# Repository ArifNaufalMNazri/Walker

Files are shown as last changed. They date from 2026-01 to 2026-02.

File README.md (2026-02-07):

# Walker

<p align="center"> 
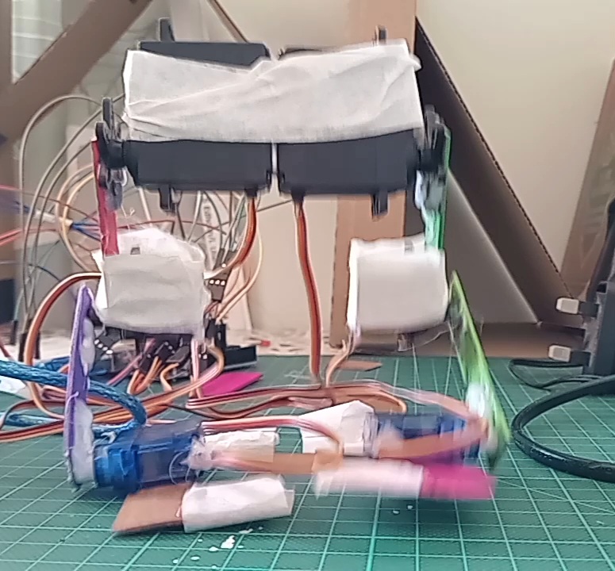
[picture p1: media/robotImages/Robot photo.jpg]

</p>

## Project Overview 🔍
I created a 2-legged walking robot to learn how inverse kinematics works, robot design, and motor control. This project is intended as an experiment to explore robotics and moving systems. 

## Repository files 📁
- /designs: Designs for the robot, including sketches and CAD
- /code: Test code for the robot
- /media: Photos and videos of tests

## Problems I solved & Build process🗒️

### Design

- I had to come up with designs for the robot. I started with an initial sketch of the robot, shown in the link below.

➡️ [View Iteration 1](https://github.com/ArifNaufalMNazri/Walker/blob/main/designs/iteration1/README.md)

- I represented the drawing in CAD to better visualize it. 

➡️[View Iteration 2](https://github.com/ArifNaufalMNazri/Walker/blob/main/designs/iteration2/README.md)

### Leg Prototype

- With the design completed, I moved on to building a prototype leg to test movement. 

➡️[View Iteration 1](https://github.com/ArifNaufalMNazri/Walker/blob/main/protoLeg/iteration1/README.md)

- I conducted button tests with the leg to see how each servo moved. 

➡️[View Iteration 2](https://github.com/ArifNaufalMNazri/Walker/blob/main/protoLeg/iteration2/README.md)

- Kinematics equations were derived and implemented into the program. A new stand for leg testing was built to test more dynamic movement.

➡️[View Iteration 3](https://github.com/ArifNaufalMNazri/Walker/blob/main/protoLeg/iteration3/README.md)

- The hip servo was not handling the weight well, so it was replaced witha stronger servo. New stand made of cardboard was made for transportability.

➡️[View Iteration 4](https://github.com/ArifNaufalMNazri/Walker/blob/main/protoLeg/iteration4/README.md)

- The calculations for movement in the negative x-axis were corrected and a basic triangle-stepping sequence was tested

➡️[View Iteration 5](https://github.com/ArifNaufalMNazri/Walker/blob/main/protoLeg/iteration5/README.md)

- I added the ankle servo and calculated new equations to determine its angle in space

➡️[View Iteration 6](https://github.com/ArifNaufalMNazri/Walker/blob/main/protoLeg/iteration6/README.md)

### Final Robot
I connected the two servos with duct tape and used a new stepping sequence for walking. Finally, the robot walked as intended, albeit shakily. The experiment was deemed a success. 

<p align="center">
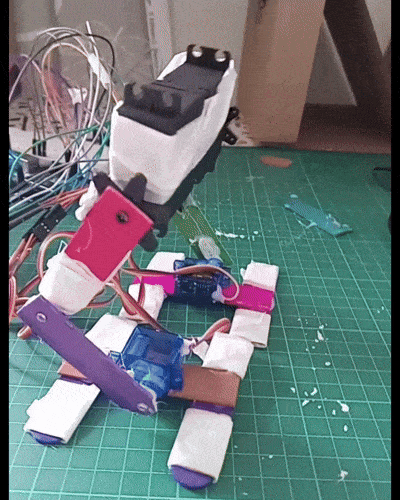
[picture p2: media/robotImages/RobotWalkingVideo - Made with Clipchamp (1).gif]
  
</p>

Link to code: ➡️[View Code](https://github.com/ArifNaufalMNazri/Walker/blob/main/WalkerCode.ino)

## Last thoughts 🧠
I am glad that the robot managed to walk on its own two feet. It is my first experiment into moving robot systems, so I was not surprised it came off a bit shaky. The problems I solved, however, taught me a lot about trigonometry, code, inverse kinematics and motor control. I plan to use this knowledge and more to create even better projects in the future. That's all from me for now. Thank you for reading.

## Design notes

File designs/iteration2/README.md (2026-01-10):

# Iteration2-CAD design using FreeCAD

## Sample image 
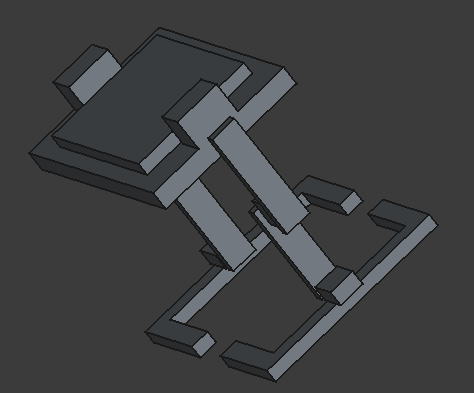
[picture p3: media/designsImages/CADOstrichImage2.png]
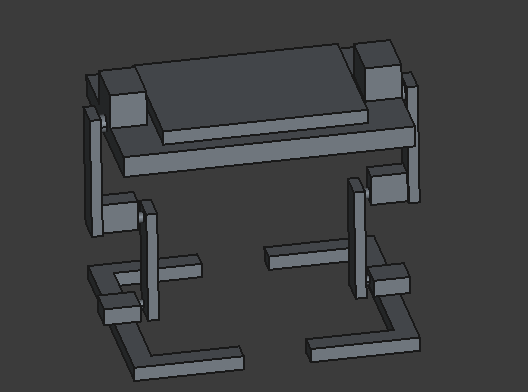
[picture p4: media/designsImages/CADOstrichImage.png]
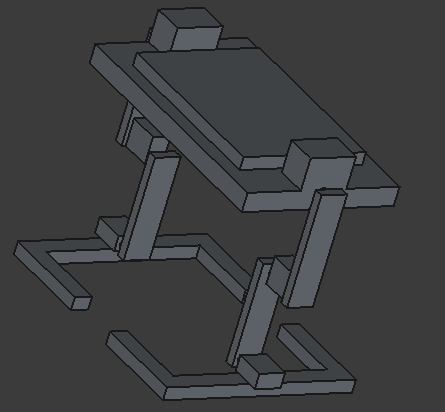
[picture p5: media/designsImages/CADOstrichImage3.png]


CAD file link: [CADFile](https://github.com/ArifNaufalMNazri/Walker/blob/main/designs/iteration2/ProjectOstrich.step)

<i>Access file in FreeCAD</i>

## Description
-The flat rectangle on top of the robot is meant to represent the **Arduino UNO**

-The feet was designed based on toy robots to **improve stability and reduce weight**

-The cuboids with cylinders popping out represent the **servos**

## What's next
I'm satisfied with how the design looks. I think this is the end of my first design process, and I'll now proceed to building a **prototype leg.**

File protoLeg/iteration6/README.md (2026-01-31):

# Third servo-Update servo angle functions-Angle orientation-Second leg
A lot happened in this iteration. Let's go through them one by one. 
## Third servo
I added the third servo by orienting it at 90 degrees and putting it on its side, screwing it into the leg. 
<p align="center">
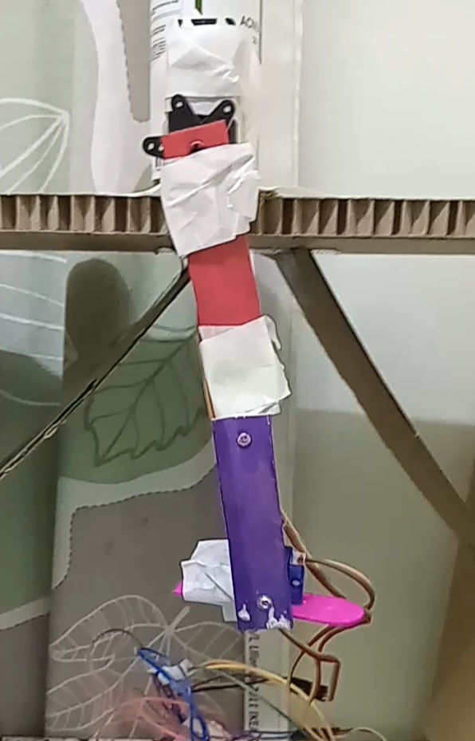
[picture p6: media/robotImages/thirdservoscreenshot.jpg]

</p>

## Update servo angle functions
I created new functions to update the servos positions so they all can change at the same rate. They are called `step()` and `updateAngle()`
Further explanations are in comments in the code. 
<p align="center">
  
<i>step()</i>
  
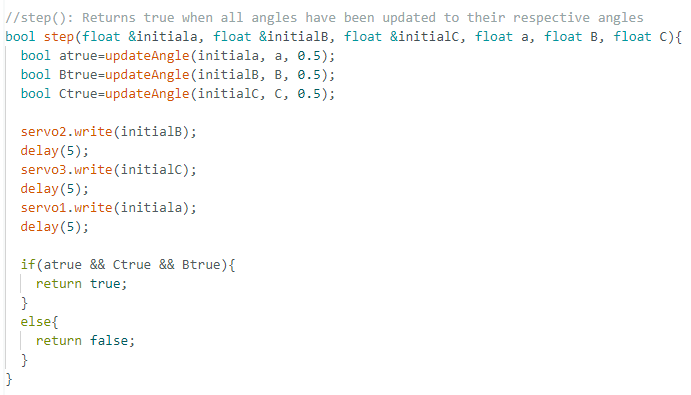
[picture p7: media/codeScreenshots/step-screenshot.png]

</p>

<p align="center">
  
<i>updateAngle()</i>

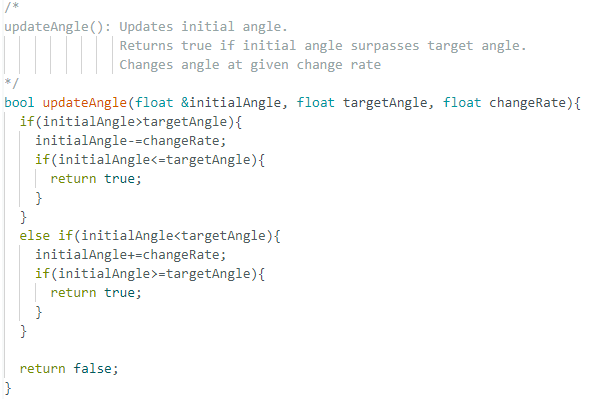
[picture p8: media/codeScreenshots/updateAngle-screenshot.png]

</p>

[Get code here](https://github.com/ArifNaufalMNazri/Walker/blob/main/code/legTestsCode2/legTests.ino)

## Angle orientation
I changed the leg lengths to be equal to form an isosceles triangle, making the calculations easier. I first started with updating the third servo angle as the leg was straight. 

<p align="center">
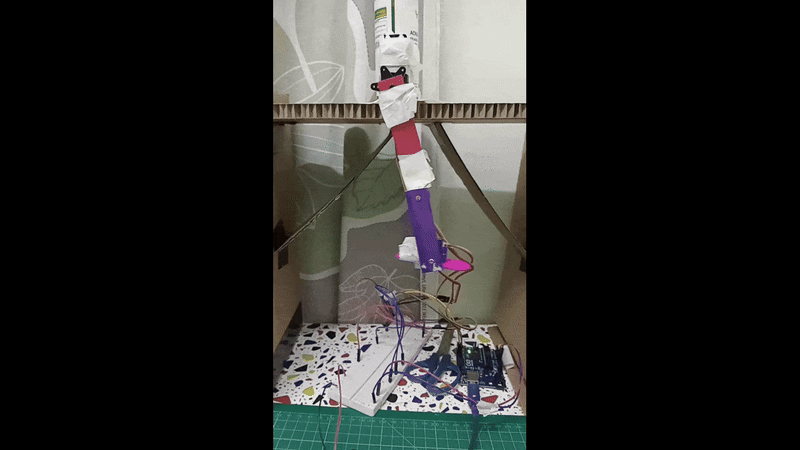
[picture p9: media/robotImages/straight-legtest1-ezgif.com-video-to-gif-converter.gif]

</p>

Once I finished orienting that, I moved on to making the leg move up and down and maintaing the third servos parallel angle against the ground. 

<p align="center">
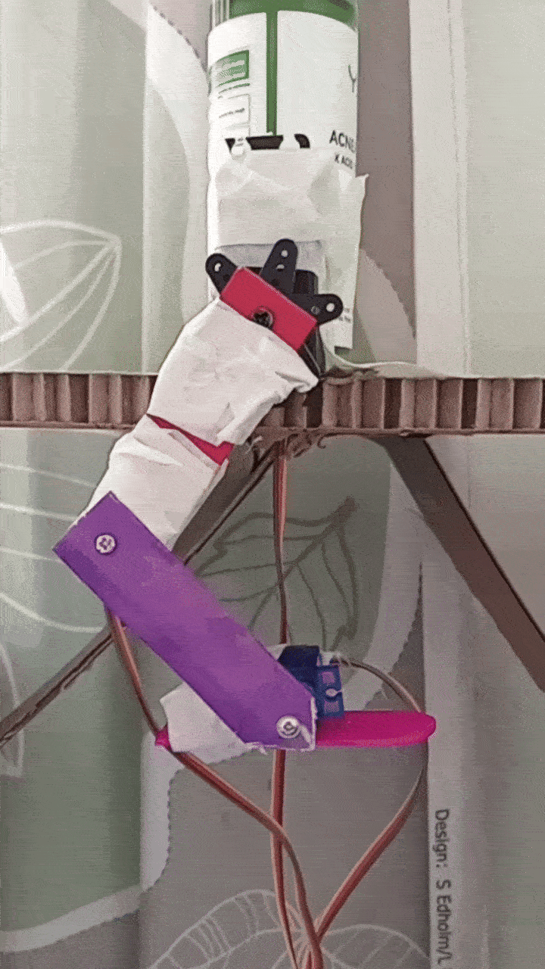
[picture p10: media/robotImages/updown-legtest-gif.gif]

</p>

By adding a function `findC()` into the kinematics file, I could calculate the angle for the third servo.

<p align="center">

<i>findC</i>

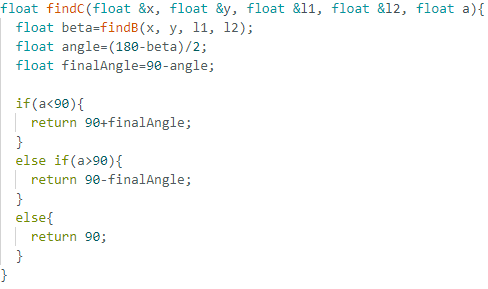
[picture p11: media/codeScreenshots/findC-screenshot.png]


</p>

## The second leg 
After I finished orienting the angles of the third servo, I built an identical leg as the first one to serve as the second leg
<p align="center">
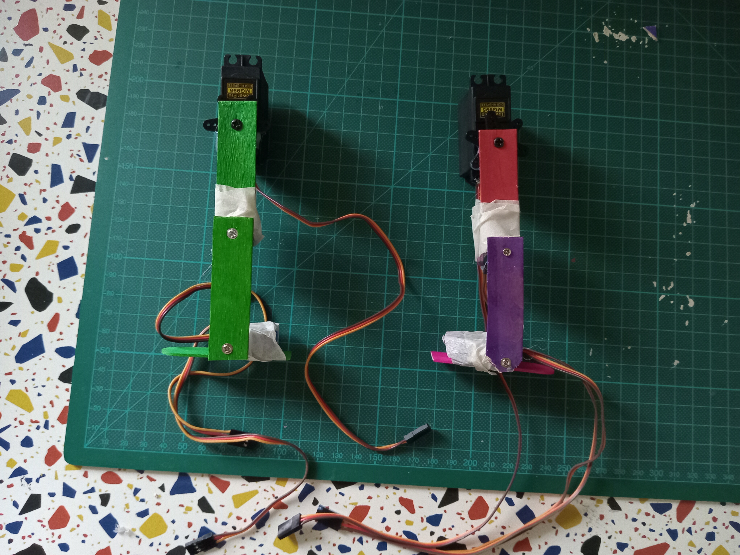
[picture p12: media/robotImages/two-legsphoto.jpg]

  
<i>Second leg on left, first leg on right</i>
</p>

## What's next
I am going to do some final tests with the first and second leg to see whether all the angles are calculated correctly. Then, afterwards, I'll start building the actual robot. The project is nearing completion.

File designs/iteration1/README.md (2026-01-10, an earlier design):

# Iteration1-First Ideas
## What I wanted
I wanted to make a something simple that I knew could walk and stand upright. Searching through the internet gave me some ideas for early sketches, like the Leggy and the Ducky.

## Design Idea
Eventually, I was inspired by the way ostriches moves, and hence, I designed the Ostrich based on its leg movements. The leg is designed to bend inwards, which might present a challenge for generating the walking sequence. Nevertheless, I have chosen this design: 

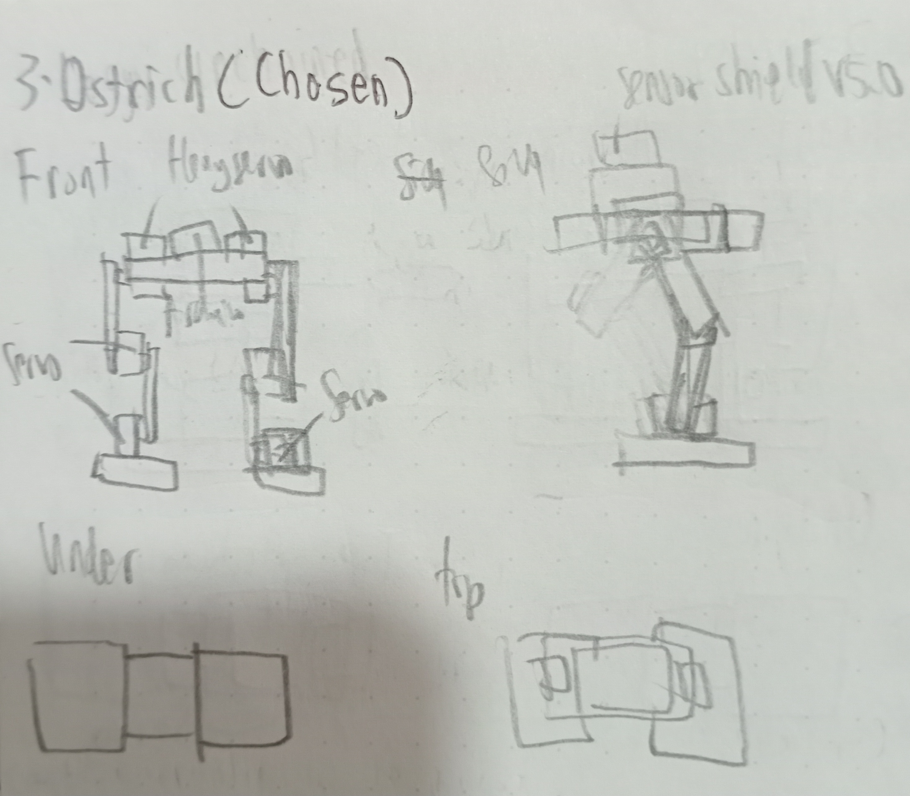
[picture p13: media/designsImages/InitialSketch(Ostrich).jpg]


### The previous sketches
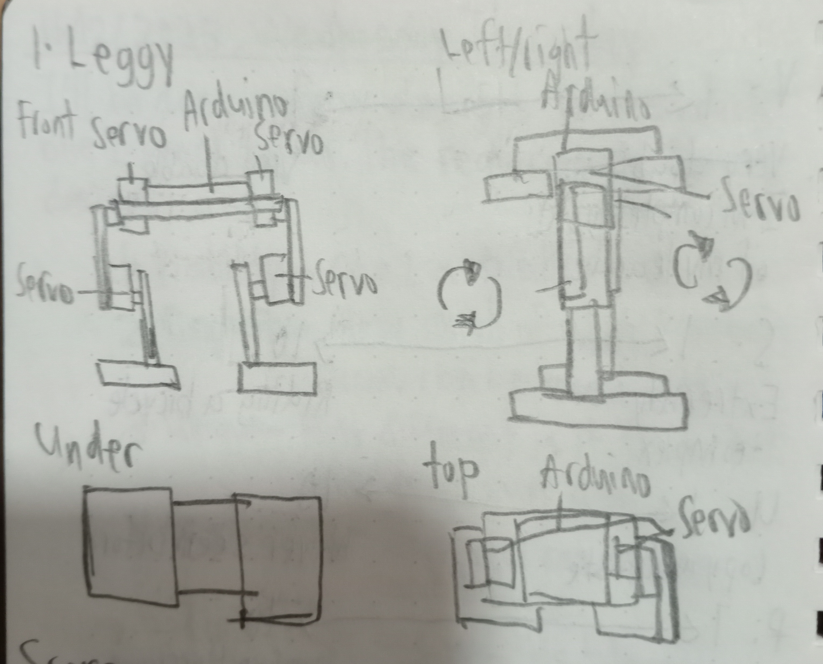
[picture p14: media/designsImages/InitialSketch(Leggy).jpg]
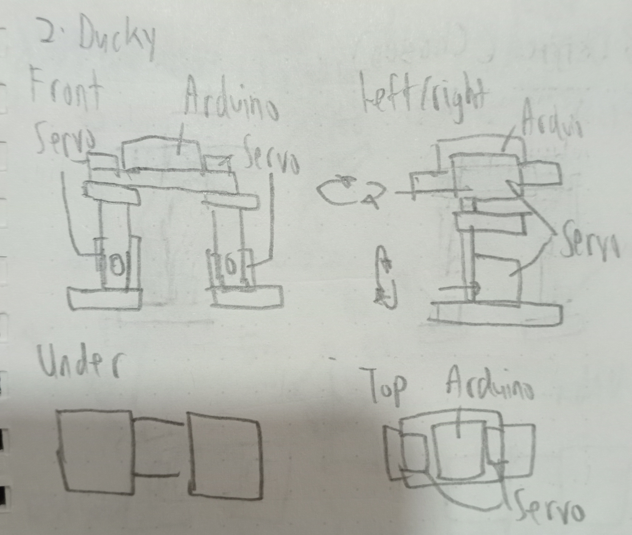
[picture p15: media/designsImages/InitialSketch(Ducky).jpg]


## What Next?
I'll try making a CAD of this sketch so I can practice my CAD skills and see a 3d model of the robot itself

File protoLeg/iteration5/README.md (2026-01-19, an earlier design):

# Stepping tests--Negative x_axis and Triangle Step
I adjusted my code so that I could make the leg move in the negative x-axis, tried out a triangular stepping sequence, and adjusted my stand
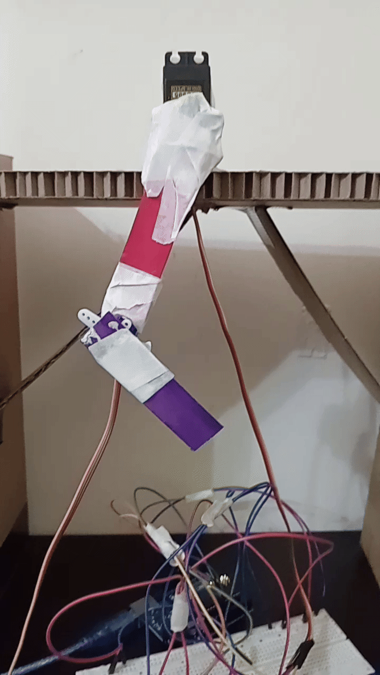
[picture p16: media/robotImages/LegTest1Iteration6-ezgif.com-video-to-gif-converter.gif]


## Adjusting my stand
I added supports underneath my stand so it would not shake as theleg swung
<p align="center">
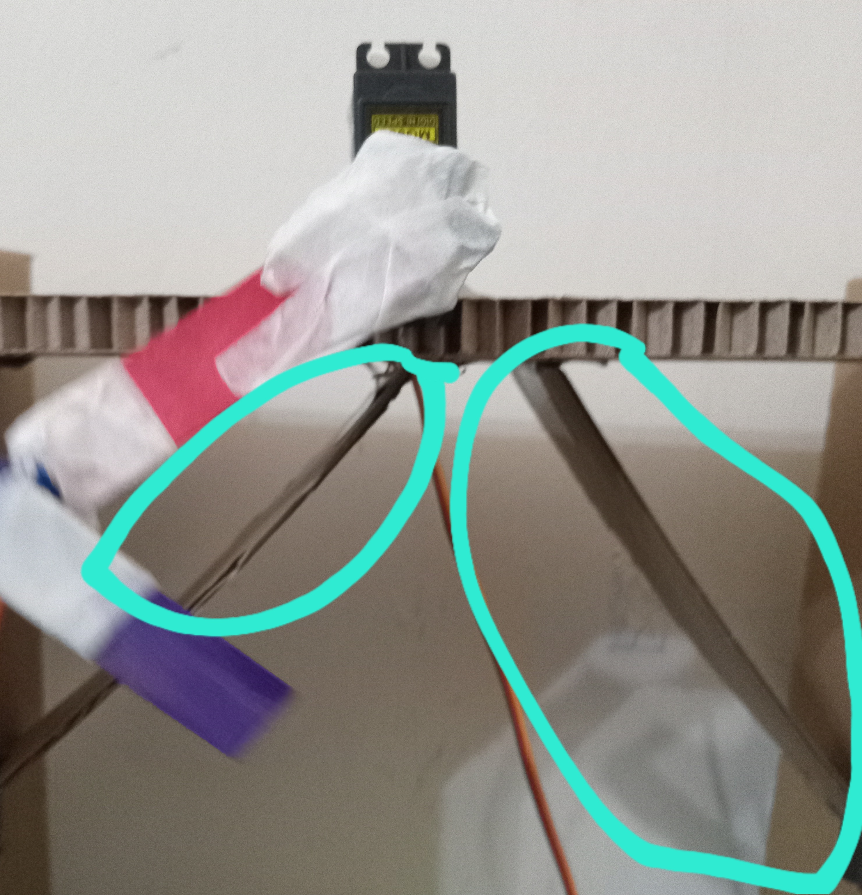
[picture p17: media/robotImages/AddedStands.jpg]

</p>

## Code adjustments
I changed how my code took in -x values so that it would return a different value for the servo angles. BY changing what angles I took and what I subtracted, I was able to correctly transalate the position of the foot in the -x axis. 
<p align="center">
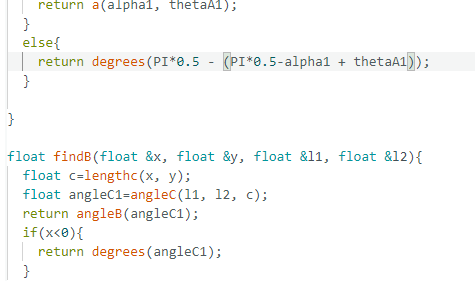
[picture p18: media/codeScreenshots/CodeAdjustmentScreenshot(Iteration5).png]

</p>

| Positive x-axis | Negative x-axis |
|:---:|:---:|
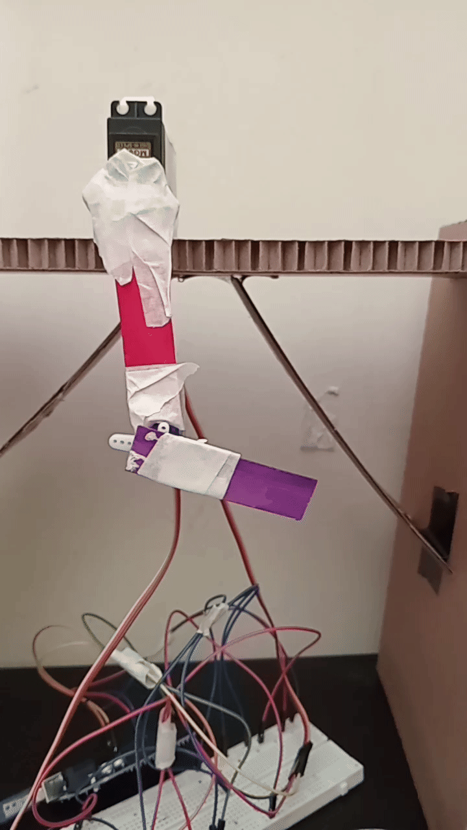
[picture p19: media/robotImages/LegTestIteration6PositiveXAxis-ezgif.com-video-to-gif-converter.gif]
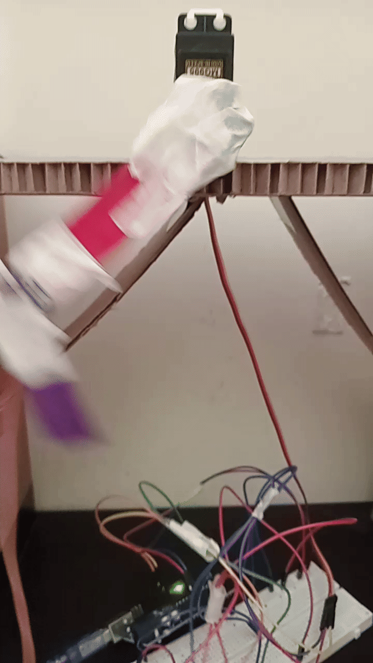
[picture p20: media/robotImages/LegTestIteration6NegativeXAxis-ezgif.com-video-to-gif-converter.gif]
|||

## Triangle Stepping Sequence
Afterwards, I created a function that took two x and y values, one for the triangles step, and one for the homing step. The triangle step caused the foot to move in a triangle based on the kinematics calculations. The homing step gave the triangle the third point it needed to create a triangle, and also served as an anchor position for the foot for reference. 
<p align="center"><i>Triangle step function</i></p>
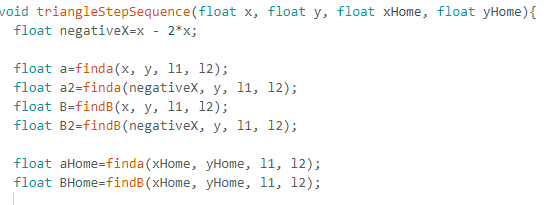
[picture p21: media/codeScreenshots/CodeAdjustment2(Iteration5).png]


<p align="center"><i>Leg triangle step(Video was cut off, but the actual video shows the leg moving to its homing position after travelling to the -x axis</i></p>
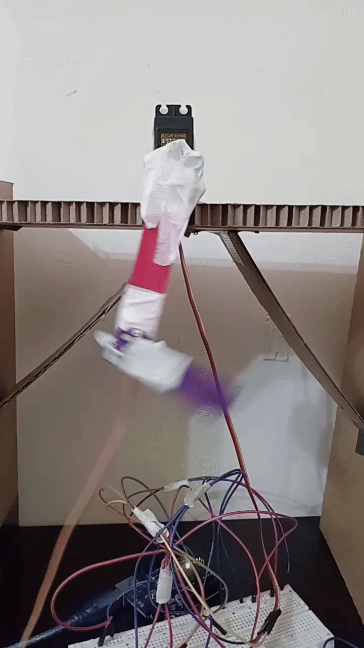
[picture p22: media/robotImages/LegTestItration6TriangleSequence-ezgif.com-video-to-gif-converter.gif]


## What's next
I'm planning on finally integrating the foot servo into the leg. I'll have to create new functions and workout new equations to allow the foot to always maintain its 90 degree angle position. 
- Integrate 3rd Servo to leg
- Create new kinematics equation to allow 3rd servo to maintain 90 degree orientation
- Transalate calculations into code

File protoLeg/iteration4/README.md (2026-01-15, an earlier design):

# Iteratioin4-New Stand 2 and New Servo
## The new stand-Part 2
I built a new stand made of cardboard I had from Ikea-furniture packaging. It was designed to be **stable** and **transportable**. I like how comfortable and easy it is to bring around now. 

| Front View | Left View | Right-Top View |
|:---:|:---:|:---:|
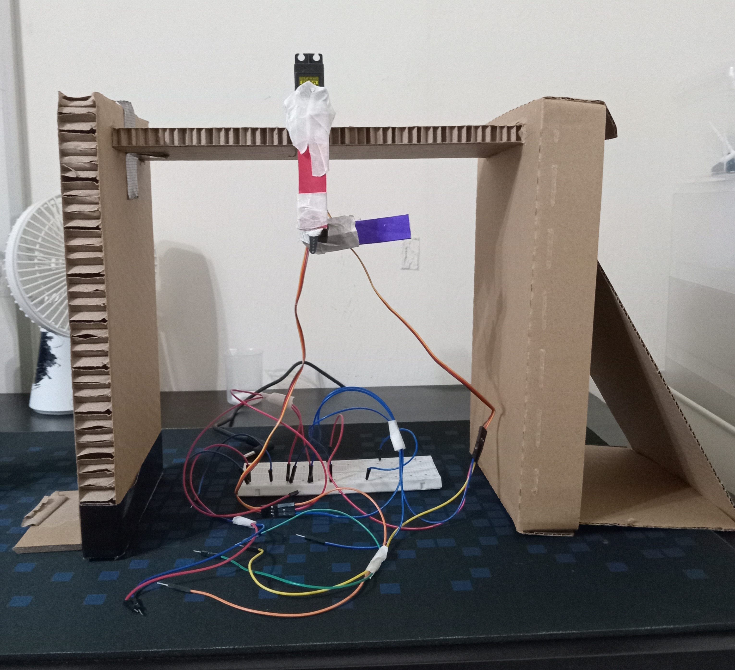
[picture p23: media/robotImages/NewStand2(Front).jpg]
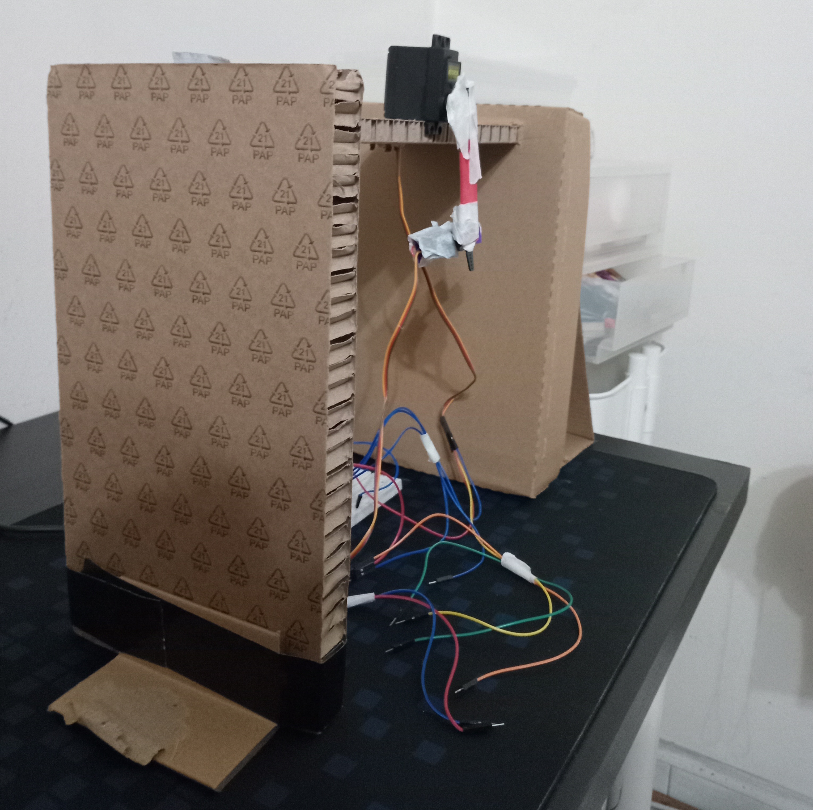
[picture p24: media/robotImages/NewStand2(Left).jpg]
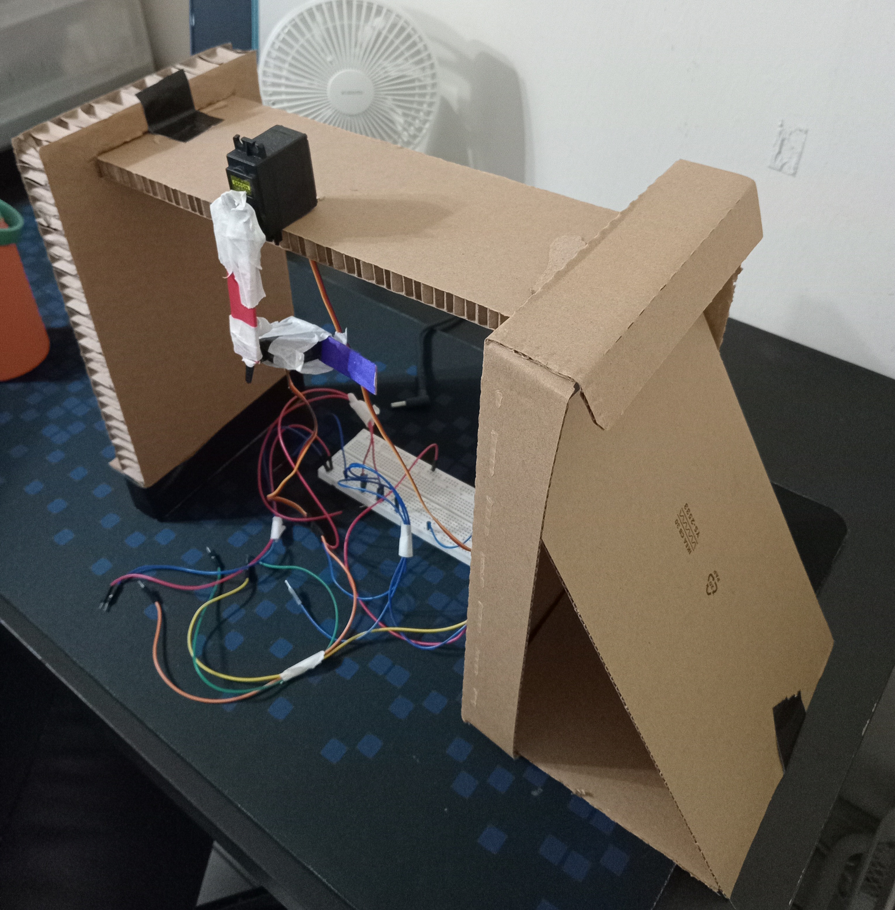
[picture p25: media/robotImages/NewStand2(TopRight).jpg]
||||

## The new Servo
I bought a stronger servo for the hip servo, and used the previous hip servo as the now knee servo

<p align="center">
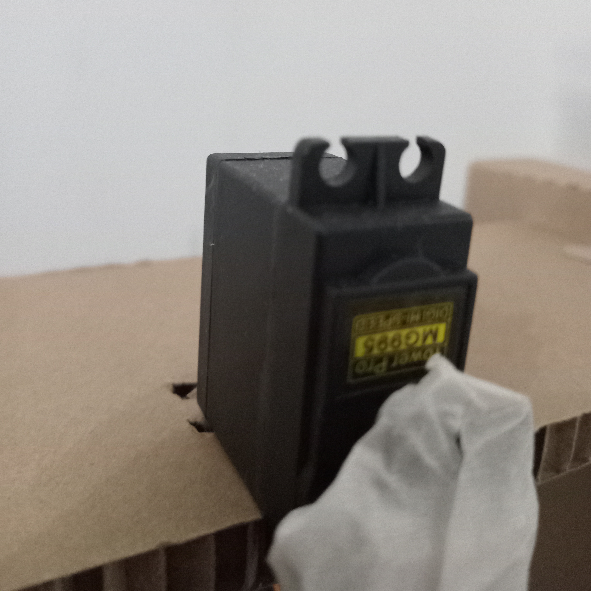
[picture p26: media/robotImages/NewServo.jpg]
  
</p>

## What's next
- Test the kinematics program on the new leg
- Make adjustments as needed
- Reintegrate the foot joint

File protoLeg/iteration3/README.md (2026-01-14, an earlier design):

# Iteration3-Test Kinematics and New Leg Stand
## Kinematics calculations
I needed a way to calculate the angles the servos needed to turn in order to change the foot's position. In order to do that, I ignored the turning the foot for now and focused more on turning the hip and knee servos. Here are the diagrams of my calculations: 

<p>




</p>

<i>Images clearer in media folder</i>

## Description
I used **cosine** and **sin** rules in my calculations, along with a coordinate system to get the desired angles. All the angles calculated lead up to the calculation of angle a and b. I also broke down the calculations step by step, which made it easier for me to transalate it into code. 



## Changing the leg stand
I realized the leg stand I used on my cupboard was too flimsy, so I changed it to balance on a stick laying between a lamp and a tissue box, which do not appear in this photo. 

<p align="center">
  <i>Old stand</i>
</p>
<p align="center">

</p>

<p align="center">
  <i>New stand</i>
</p>
<p align="center">

</p>

## Problems encountered
- **Hip** servo too **weak** to carry weight of leg and **jitters**. Need to replace with stronger servo
- New stand **uncomfortable** to move around and **weak**. Need to build a stronger one.
- Remove ankle servo for testing

## What's next
- Buy a **stronger servo** to replace the hip servo.
- Build **new stand** for leg testing

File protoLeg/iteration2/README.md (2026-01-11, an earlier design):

# Iteration2-Button test on first prototype leg
## Sample video


## Description

- Attached the leg to a cupboard so leg movement could be seen

- Moved each joint during testing (ankle joint movement not shown in video)

- Link to code: [View code](https://github.com/ArifNaufalMNazri/Walker/blob/main/code/legButtonTest.ino)

## Problems encountered
The knee servo moved in the <i>opposite</i> direction to the other servos because of its orientation. This prevented me from creating a function that would update the angle of the servos, so I resorted to this long chain of <i>if-else statements</i>: 



## What's next
I'm currently happy with how the leg moves. I'll leave the servo orientation as it is now, but I might have to change it in the future. Next, I'll work on: 
- Inverse kinematics calculations
- Putting the inverse kinematics calculations into code

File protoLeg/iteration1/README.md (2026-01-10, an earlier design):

# Iteration 1-First Prototype Leg
## Sample image


## Description
-Two SG90 Servos

-One MG90 Servo

-Three popsicle sticks

I used an MG90 servo as the **hip servo**, and the 2 SD90 servos for the **knee** and **ankle** joints. The popsicles of the femur and tibia were both **7cm**, while the foot was of **unrecorded** length

## Up next
Now, I want to attach this to the arduino and write a simple program to change the angles of the servos by pushing **buttons**. It will help me to see what positions I want the leg to move to, and confirm whether the leg can move as expected.

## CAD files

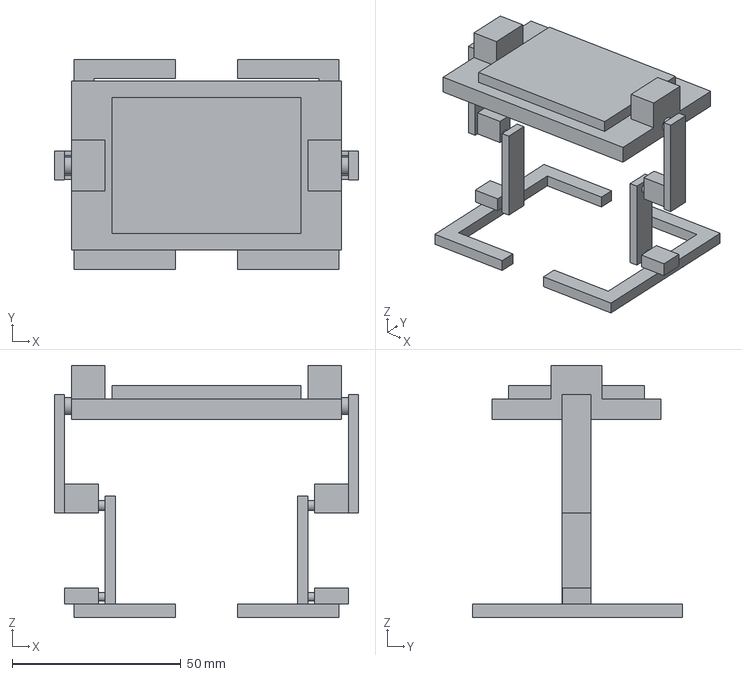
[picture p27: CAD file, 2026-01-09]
designs/iteration2/ProjectOstrich.step
90.0 x 62.2 x 74.7 mm

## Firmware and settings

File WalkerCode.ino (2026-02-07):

#include "kinematics.h"
#include <Servo.h>

//Servo pins
const int ServoPin1=8;
const int ServoPin2=9;
const int ServoPin3=10;
const int ServoPin4=5;
const int ServoPin5=6;
const int ServoPin6=7;

//Servo objects
Servo servo1;
Servo servo2;
Servo servo3;
Servo servo4;
Servo servo5;
Servo servo6;

//Length of legs. Equal to form isosceles triangle
float l1=5.2;
float l2=5.2;

//Initial position of servos
float initialx=0;
float initialy=-9;

float x=2;
float y=-6;

float x2=3;
float y2=-9;

void setup() {

  servo1.attach(ServoPin1);
  servo2.attach(ServoPin2);
  servo3.attach(ServoPin3);
  servo4.attach(ServoPin4);
  servo5.attach(ServoPin5);
  servo6.attach(ServoPin6);

  float a=finda(initialx, initialy, l1, l2);
  float B=findB(initialx, initialy, l1, l2);
  float C=findC(initialx, initialy, l1, l2, a);

  servo1.write(a);
  servo2.write(B);
  servo3.write(C);
  servo4.write(180-a);
  servo5.write(180-B);
  servo6.write(180-C);

  delay(1000);

}


/*
updateAngle(): Updates initial angle. 
               Returns true if initial angle surpasses target angle. 
               Changes angle at given change rate
*/
bool updateAngle(float &initialAngle, float targetAngle, float changeRate){
  if(initialAngle>targetAngle){
    initialAngle-=changeRate;
    if(initialAngle<=targetAngle){
      return true;
    }
  }
  else if(initialAngle<targetAngle){
    initialAngle+=changeRate;
    if(initialAngle>=targetAngle){
      return true;
    }
  }

  if(initialAngle==targetAngle){
    return true;
  }

  return false;
}


//step(): Returns true when all angles have been updated to their respective angles
bool step(float &initiala, float &initialB, float &initialC, float a, float B, float C, int mode){
  bool atrue=updateAngle(initiala, a, 0.5);
  bool Btrue=updateAngle(initialB, B, 0.5);
  bool Ctrue=updateAngle(initialC, C, 0.5);

  float delaytime=3;
  
  if(mode==1){
  servo2.write(initialB);
  delay(delaytime);
  servo3.write(initialC);
  delay(delaytime);
  servo1.write(initiala);
  delay(delaytime);
}
else if(mode==2){
  servo5.write(180-initialB);
  delay(delaytime);
  servo6.write(180-initialC);
  delay(delaytime);
  servo4.write(180-initiala);
  delay(delaytime);
}
  if(atrue && Ctrue && Btrue){
    return true;
  }
  else{
    return false;
  }
}

//Initial angles of servos
float initiala=90;
float initialB=0;
float initialC=90;

float initiala2=90;
float initialB2=0;
float initialC2=90;

float delaytime=30;

void loop() {
    //First coordinate
    float a=finda(x, y, l1, l2);
    float B=findB(x, y, l1, l2);
    float C=findC(x, y, l1, l2, a);

    //Second coordinate
    float a2=finda(x2, y2, l1, l2);
    float B2=findB(x2, y2, l1, l2);
    float C2=findC(x2, y2, l1, l2, a2);
    
    //Third coordinate
    float a3=finda(initialx, initialy, l1, l2);
    float B3=findB(initialx, initialy, l1, l2);
    float C3=findC(initialx, initialy, l1, l2, a3);
    
    while(true){
      bool legCondition=step(initiala, initialB, initialC, a, B, 140, 1);
      if(legCondition){
        break;
      }
    } 
    
    delay(delaytime);
  
    while(true){
      bool legCondition=step(initiala, initialB, initialC, a2, B2, C2, 1);
      if(legCondition){
        break;
      }
    } 

    delay(delaytime);

    while(true){
      bool legCondition=step(initiala, initialB, initialC, a3, B3, C3, 1);
      bool legCondition2=step(initiala2, initialB2, initialC2, a, B, 140, 2);
      if(legCondition && legCondition2){
        break;
      }
    } 
    
    delay(delaytime);

    while(true){
      bool legCondition=step(initiala2, initialB2, initialC2, a2, B2 ,C2, 2);
      if(legCondition){
        break;
      }
    } 
    
    delay(delaytime);

    while(true){
      bool legCondition=step(initiala2, initialB2, initialC2, a3, B3, C3, 2);
      bool legCondition2=step(initiala, initialB, initialC, a, B, 140, 1);
      if(legCondition && legCondition2){
        break;
      }
    } 
    
    delay(delaytime);
  
}

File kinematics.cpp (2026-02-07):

#include "kinematics.h"

float limit(float x){
  return max(min(x, 1.0), -1.0);
}

float lengthc(float &x, float &y){
  return sqrt((x*x) + (y*y));
}

float alpha(float &x, float &y){
  return atan(fabs(y)/fabs(x));
}

float angleC(float &l1, float &l2, float &c){
  return acos((l1*l1 + l2*l2 - c*c)/(2*l1*l2));
}

float thetaA(float &l2, float &c, float &angleC){
  return asin((sin(angleC)*l2)/c);
}

float a(float &alpha, float &thetaA){
  return degrees((PI) - alpha - thetaA);
}

float angleB(float &angleC){
  return degrees(PI - angleC);
}

float finda(float &x, float &y, float &l1, float &l2){
  float c=lengthc(x, y);
  float alpha1=alpha(x, y);
  float angleC1=angleC(l1, l2, c);
  float thetaA1=thetaA(l2, c, angleC1);
  if(x>=0){
    return a(alpha1, thetaA1);
  }
  else{
    return degrees(PI*0.5 - (PI*0.5-alpha1 + thetaA1));
  }
  
}

float findB(float &x, float &y, float &l1, float &l2){
  float a=finda(x, y, l1, l2);
  if(a<90){
    float c1=lengthc(x, y);
    float c2=angleC(l1, l2, c1);
    return angleB(c2);
  }
  else if(a>90){
    float al=degrees(alpha(x, y));
    Serial.print("al: ");
    Serial.println(al);
    float alpha2=180-a-al;
    Serial.println(alpha2);
    float beta=180-2*alpha2;
    Serial.println(beta);
    return 180-beta;
  }
  else{
    float al=degrees(alpha(x, y));
    float alpha2=90-al;
    float beta=180-2*alpha2;
    return 180-beta;
  }
}

float findC(float &x, float &y, float &l1, float &l2, float a){
  float beta=findB(x, y, l1, l2);
  float a2=finda(x, y, l1, l2);
  float angle=(180-beta);
  float finalAngle=(180-angle)/2;
  float reflectAngle=90-finalAngle;

  if(y==5.2){
    return 90+angle;
  }

  if(a<90){
    if(x==0){
      return 90+finalAngle;
    }
    float firstAngle=90-a;
    float secondAngle=180-firstAngle-(180-beta);
    float returnValue=90+(90-secondAngle);
    Serial.println(returnValue);
    return returnValue;
  }
  else if(a>90){
    return 90+finalAngle;
  }
  else{
    return 90;
  }
}

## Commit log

2026-01-09 Enter CAD into iteration2 folder
    Image of CAD design and CAD file
    [ProjectOstrich.step]
2026-01-09 Add documentation of CAD design to iteration2
2026-01-09 Add more CAD images to iteration2
2026-01-10 Copy CAD images into media folder
2026-01-10 Update CAD image paths
    Change image location from iteration2 to media
2026-01-11 Create robotVideos folder
    To house all the videos of the test leg and the robot
2026-01-11 Add leg button test video to robot videos folder
2026-01-11 Add documentation of button leg test to iteration 2
2026-01-11 Add iteration2 of prototype leg to main README
2026-01-13 Add legTests file and kinematics file
2026-01-14 Create kinematics calculation folder in media
2026-01-14 Add kinematics calculation images to media
2026-01-14 Add kinematics code screenshot to codeScreenshots
2026-01-15 Add new stand 2 photos and new servo photo
2026-01-15 Add iteration4 of prototype Leg to main README
2026-01-19 Add leg step tests photos and gifs to media folder
